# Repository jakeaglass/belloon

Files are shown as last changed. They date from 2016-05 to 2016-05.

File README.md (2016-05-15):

##Belloon &ndash; Bellarmine College Prep's High Altitude Balloon Project &ndash; Code, Schematics, and PCB Layout

Launching in ~~winter~~ summer of 2016 (targeting ~~January~~ June) to ~35km of altitude with a 1600g Hydrogen-filled latex balloon and a sensor package complete with the following:

- Camera (GoPro HERO))
- 144.390MHz APRS RadioMetrix Radio for telemetry
- GPS tracker (model TBD)
- ATMega CPU (with Arduino bootloader) with SD card for data logging
- Gas sensors (a sensor that can detect carbon-based gases and nitrous oxide, some of the worse pollutants in the atmosphere that also cause smog)
- Humidity Sensor
- Temperature Sensor

Once the balloon's payload&mdash;the board and sensors&mdash;is complete, we'll be able to launch and make use of the data collected to study environmental changes in the Earth’s atmosphere. Launch will be carried out with the help of the California Near Space Project, which has volunteered to facilitate the launch and retrieval. 

The board design is complete as of May 12 and has been sent off to be fabricated, so it will be debugged in person shortly. See the updated files for the full schematic and board (both done in EAGLE), gerber files, and BOM.

 &ndash; [Jake Glass](http://jake.glass) & [Mihir Trivedi](http://mihirtrivedi.com/)

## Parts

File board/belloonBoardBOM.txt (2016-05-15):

Partlist

Exported from sensorBoardSchematic2.brd at 5/11/2016 8:02 PM

EAGLE Version 7.5.0 Copyright (c) 1988-2015 CadSoft

Assembly variant: 

Part              Value             Package             Library                  Position (inch)       Orientation

AN1               ANT-NSG4712-6     ANT-NSG4712-6       roundsolutions           (0.2 0.45)            R0
BAROMETER         MPL115A           LGA8                SparkFun-Sensors         (1.2 0.45)            R180
C1                100uF             EIA7343             SparkFun-Capacitors      (3.3 0.25)            R90
C2                100uF             EIA7343             SparkFun-Capacitors      (3.2 0.95)            R0
C3                10uF              EIA3216             SparkFun-Retired         (3.2 0.75)            R0
C4                10uF              EIA3216             SparkFun-Retired         (3.55 0.2)            R90
C5                0.1uF             0402-CAP            SparkFun-Retired         (3.7 0.2)             R270
C6                0.1uF             0402-CAP            SparkFun-Retired         (3.3 0.6)             R0
C7                47uF              EIA3528             SparkFun-Capacitors      (1.8 2.15)            R90
C8                0.1uF             0603-CAP            SparkFun-Capacitors      (2 1.85)              R270
C9                47uF              EIA3528             SparkFun-Capacitors      (3.6 1.05)            R0
C10               47uF              EIA3528             SparkFun-Capacitors      (3.05 0.2)            R90
C11               20pF              C0402               resistor                 (1.65 0.95)           R270
C12               20pF              C0402               resistor                 (1.4 0.95)            R270
C13               1.0uF             0603-CAP            SparkFun-Capacitors      (1.15 1.45)           R0
C14               0.1uF             0603-CAP            SparkFun-Capacitors      (2.6 0.7)             R180
C15               0.1uF             0603-CAP            SparkFun-Capacitors      (1.4 0.4)             R180
C16               1.0uF             0603-CAP            SparkFun-Capacitors      (1.35 0.65)           R0
C17               10uF              0603-CAP            SparkFun-Capacitors      (0.6 1.15)            R90
C18               10uF              0603-CAP            SparkFun-Capacitors      (2.6 0.85)            R180
C19               10uF              0603-CAP            SparkFun-Capacitors      (1.4 0.5)             R180
C20               10uF              0603-CAP            SparkFun-Capacitors      (2.15 1.85)           R270
C21               0.1uF             0603-CAP            SparkFun-Capacitors      (2.05 1.6)            R90
C22               10uF              0603-CAP            SparkFun-Capacitors      (0.6 1.5)             R90
C23               .1uF              0603-CAP            SparkFun-Capacitors      (0.75 1.5)            R90
C24               10uF              0603-CAP            SparkFun-Capacitors      (2.15 0.25)           R180
C25               10uF              0603-CAP            SparkFun-Capacitors      (1.65 0.25)           R180
C26               10uF              0603-CAP            SparkFun-Capacitors      (0.5 0.15)            R90
C27               0.1uF             0402-CAP            SparkFun-Retired         (3 1.45)              R270
C28               0.1uF             0603-CAP            SparkFun-Capacitors      (1.3 1.95)            R180
CASE_GROUND_PLANE                   3,81/1,4            wirepad                  (0.5 2.4)             R0
HUMIDITY          HDC1050           TI-S-PWSON-N6       Ava                      (2.75 0.8)            R90
IC1               RXM-GPS-FM        SMD-22              linx-addl                (0.95 0.6)            R270
JP1                                 1X06                pinhead                  (0.35 1.95)           R90
JP2                                 1X08                pinhead                  (0.15 2.05)           R90
L1                10uH              1007                SparkFun-Passives        (2.15 1.6)            R0
LM1117I_3.3V                        SOT223              SparkFun-PowerIC         (2.75 0.2)            R90
LM1117I_5V                          SOT223              SparkFun-PowerIC         (3.2 1.25)            R0
MPU               ATMEGA32U4TQFP-44 TQFP44              SparkFun-DigitalIC       (1.65 1.65)           R0
Q1                8MHz              HC49U70             crystal                  (1.55 1.2)            R0
R1                82                0402-RES            SparkFun-Passives        (2.05 0.8)            R270
R2                51                0402-RES            SparkFun-Passives        (1.7 0.7)             R90
R3                82                0402-RES            SparkFun-Passives        (2.15 0.7)            R270
R4                47k               0402-RES            SparkFun-Passives        (2.3 0.75)            R90
R5                22                0402-RES            SparkFun-Passives        (0.85 1.4)            R180
R6                22                0402-RES            SparkFun-Passives        (0.9 1.2)             R180
R7                4.7k              0402-RES            SparkFun-Passives        (2.3 0.95)            R270
R8                4.7k              0402-RES            SparkFun-Passives        (2.15 0.95)           R270
R9                22k               0402-RES            SparkFun-Passives        (2.4 0.75)            R90
R10               82                0402-RES            SparkFun-Passives        (1.8 0.7)             R270
R11               10k               0402-RES            SparkFun-Passives        (1.6 0.7)             R90
S1                                  TACTILE-PTH         SparkFun-Retired         (2.6 1.2)             R0
T1                                  SOT-23              zetex                    (1.95 0.65)           R180
U$1               RADIOMETRIX-HX1   RADIOMETRIX-HX1     Ava                      (1.55 2.75)           R0
U$2               MICS-4514         MICS_10-SMD         SparkFun-Sensors         (2.2 0.45)            R0
U$3               MICS-2614         MICS_10-SMD         SparkFun-Sensors         (1.75 0.45)           R0
U1                                  SOT95P275X110-6N    NXP_By_element14_Batch_1 (0.65 1.3)            R0
V_BATT_6V                           SCREWTERMINAL-5MM-2 SparkFun-Connectors      (3.7 0.8)             MR270
X1                APRS_ANT          R141426             con-coax                 (0.35 2.85)           R0
X2                USB_PGRM          32005-201           con-cypressindustries    (0.3 1.3)             R0
X3                SDBMF             SDBMF-009XXBXX2     farnell                  (3.3 2.45)            R180

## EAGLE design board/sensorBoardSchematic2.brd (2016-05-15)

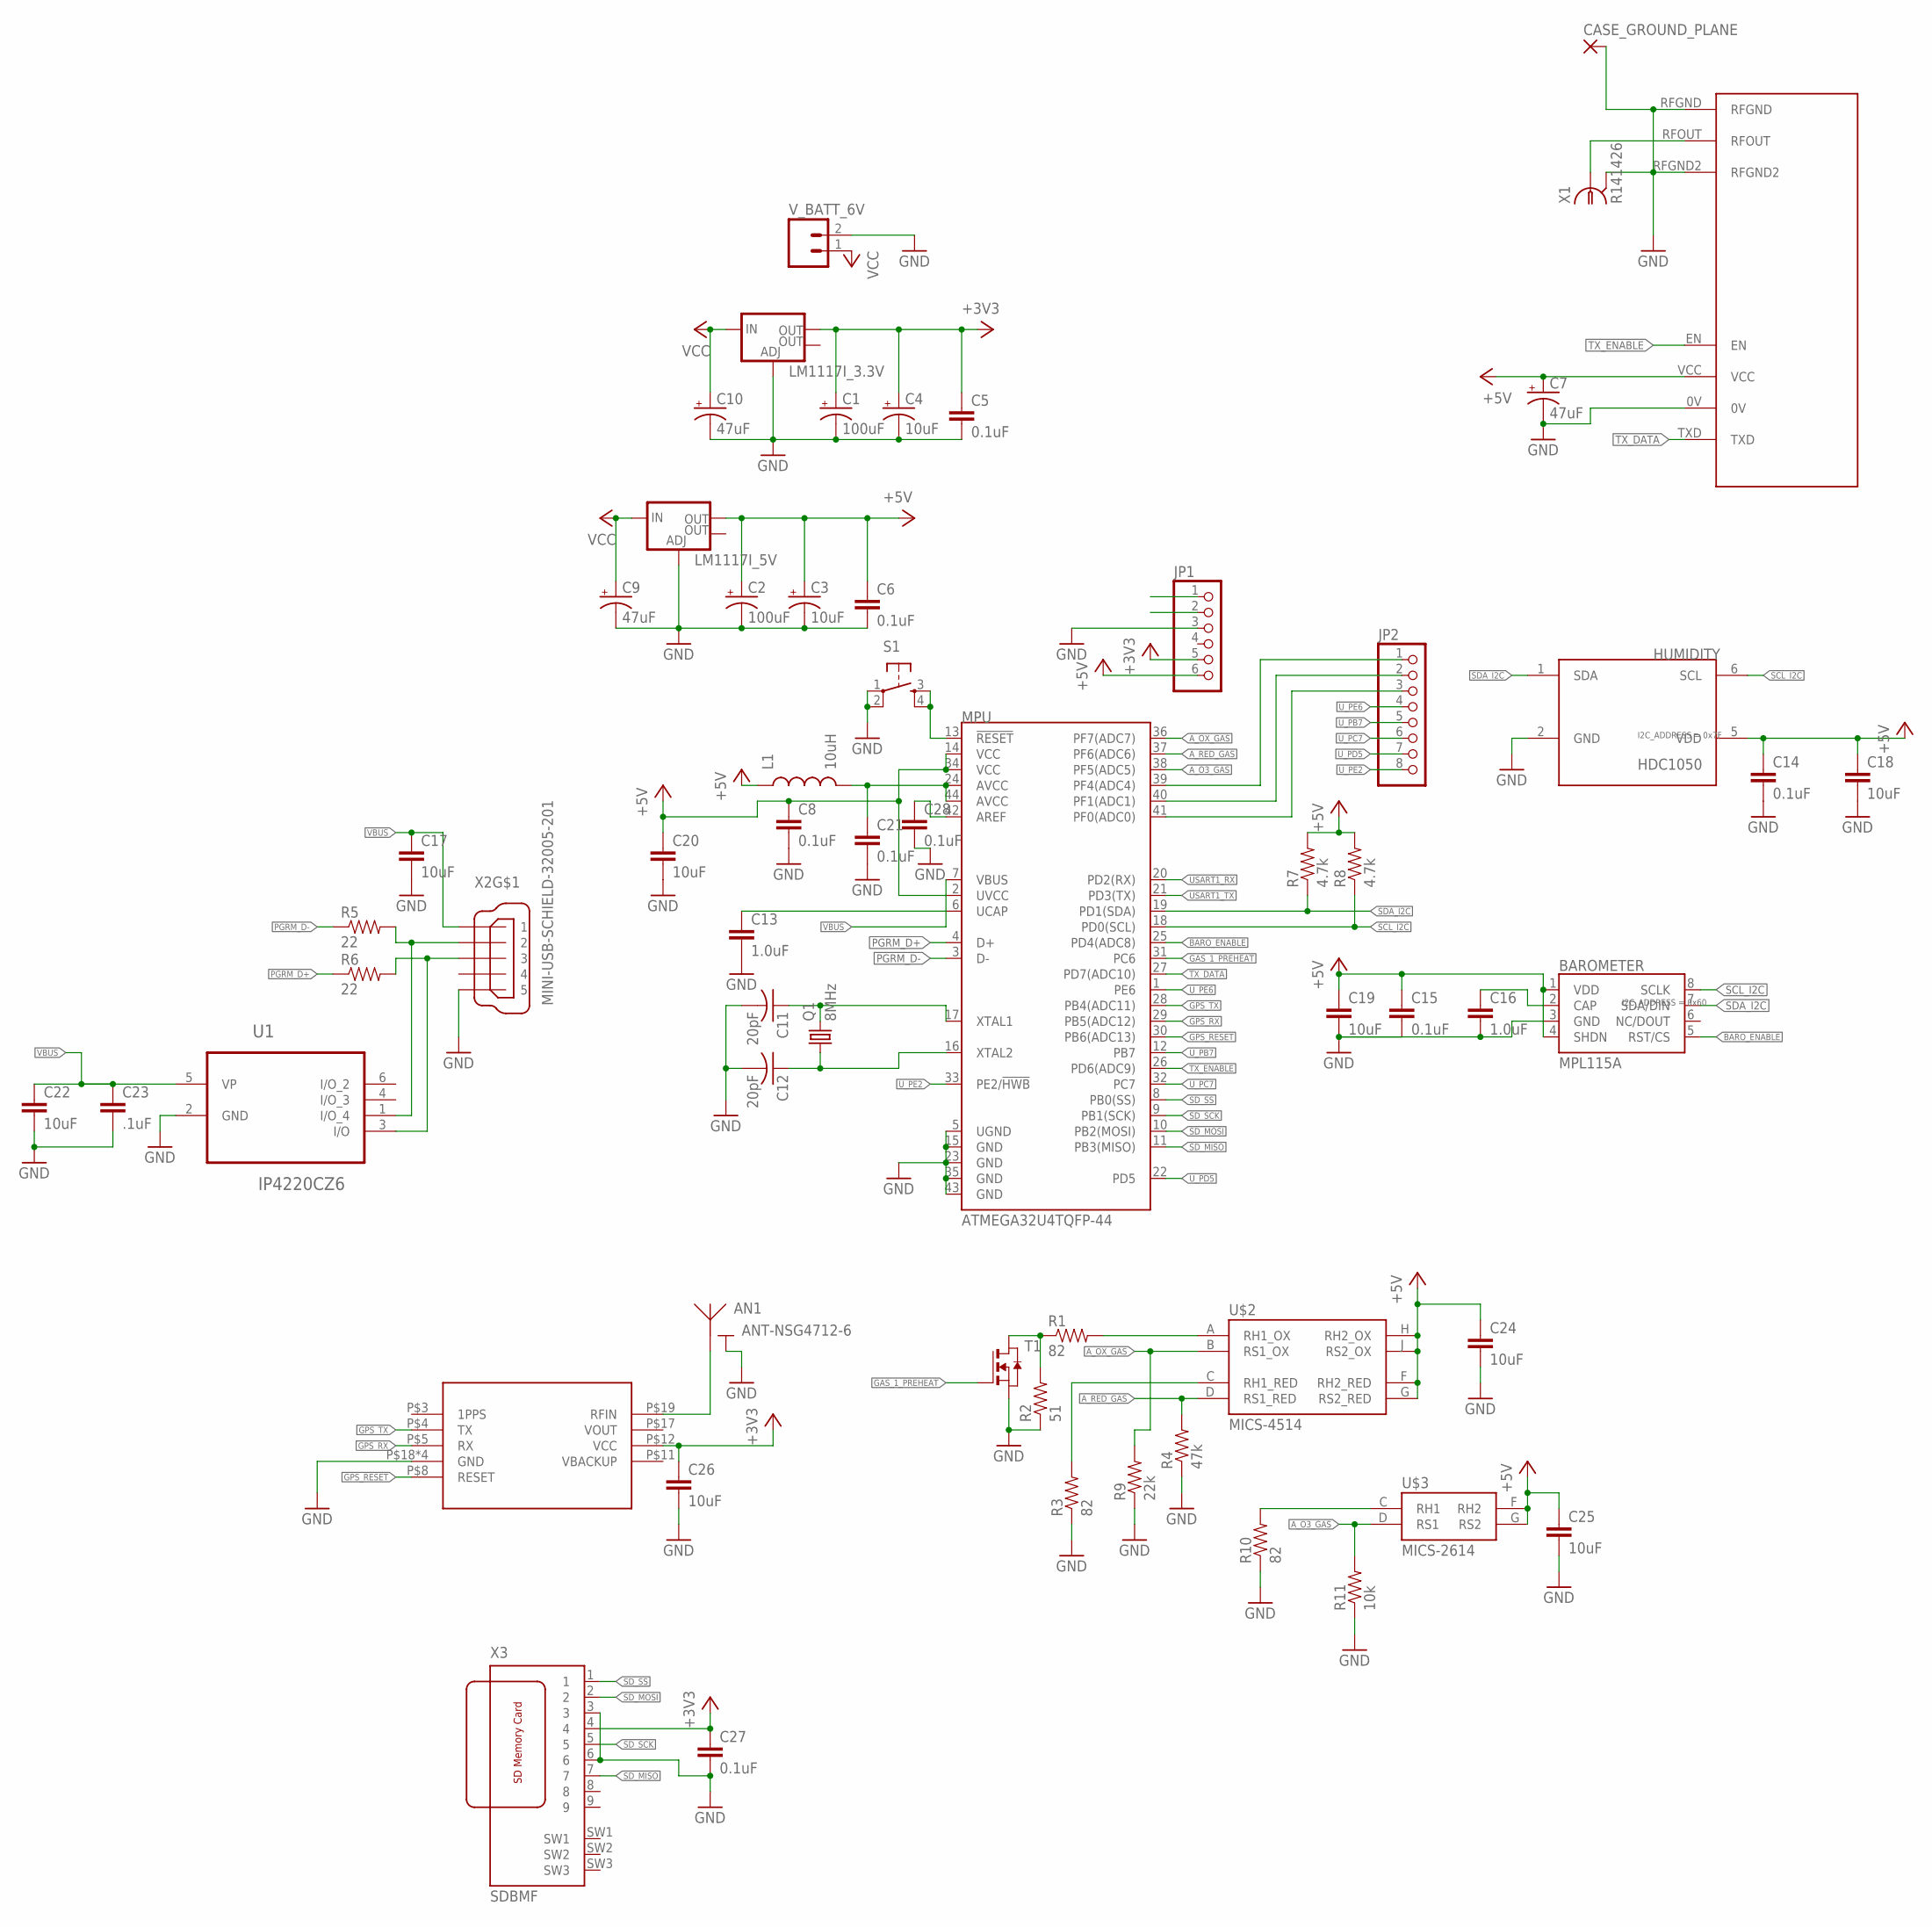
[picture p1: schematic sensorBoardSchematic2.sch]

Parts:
AN1: ANT-NSG4712-6
BAROMETER: MPL115A; LGA8
C1, C2: 100uF; EIA7343
C3, C4: 10uF; EIA3216
C5, C6, C27: 0.1uF; 0402-CAP
C7, C9, C10: 47uF; EIA3528
C8, C14, C15, C21, C28: 0.1uF; 0603-CAP
C11, C12: 20pF; C0402
C13, C16: 1.0uF; 0603-CAP
C17, C18, C19, C20, C22, C24, C25, C26: 10uF; 0603-CAP
C23: .1uF; 0603-CAP
CASE_GROUND_PLANE: 3,81/1,4
HUMIDITY: HDC1050; TI-S-PWSON-N6
IC1: RXM-GPS-FM; SMD-22
JP1: PINHD-1X6; 1X06
JP2: PINHD-1X8; 1X08
L1: 10uH; 1007
LM1117I_3.3V, LM1117I_5V: V_REG_LM1117SOT223; SOT223
MPU: ATMEGA32U4TQFP-44; TQFP44
Q1: 8MHz; HC49U70
R1, R3, R10: 82; 0402-RES
R2: 51; 0402-RES
R4: 47k; 0402-RES
R5, R6: 22; 0402-RES
R7, R8: 4.7k; 0402-RES
R9: 22k; 0402-RES
R11: 10k; 0402-RES
S1: TAC_SWITCHPTH; TACTILE-PTH
T1: NMOSSOT23; SOT-23
U1: IP4220CZ6; SOT95P275X110-6N
U$1: RADIOMETRIX-HX1
U$2: MICS-4514; MICS_10-SMD
U$3: MICS-2614; MICS_10-SMD
V_BATT_6V: M025MM; SCREWTERMINAL-5MM-2
X1: R141426
X2: MINI-USB-SCHIELD-32005-201; 32005-201
X3: SDBMF; SDBMF-009XXBXX2

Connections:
+3V3: C1.A (+), C4.A (+), C5.1, C26.1, C27.1, IC1.P$12 (VCC), JP1.5, LM1117I_3.3V.2 (OUT), X3.4
+5V: BAROMETER.1 (VDD), BAROMETER.4 (SHDN), C2.A (+), C3.A (+), C6.1, C7.A (+), C8.1, C14.1, C15.1, C18.1, C19.1, C20.1, C24.1, C25.1, HUMIDITY.5 (VDD), JP1.6, L1.1, LM1117I_5V.2 (OUT), MPU.2 (UVCC), MPU.14 (VCC), MPU.34 (VCC), R7.2, R8.2, U$1.VCC, U$2.F (RH2_RED), U$2.G (RS2_RED), U$2.H (RH2_OX), U$2.J (RS2_OX), U$3.F (RH2), U$3.G (RS2)
A_O3_GAS: MPU.38 (PF5(ADC5)), R11.2, U$3.D (RS1)
A_OX_GAS: MPU.36 (PF7(ADC7)), R9.2, U$2.B (RS1_OX)
A_RED_GAS: MPU.37 (PF6(ADC6)), R4.2, U$2.D (RS1_RED)
BARO_ENABLE: BAROMETER.5 (RST/CS), MPU.25 (PD4(ADC8))
GAS_1_PREHEAT: MPU.31 (PC6), T1.3 (G)
GND: AN1.G@1 (G), AN1.G@2 (G), AN1.G@3 (G), AN1.G@4 (G), AN1.G@5 (G), AN1.G@6 (G), AN1.G@7 (G), AN1.G@8 (G), AN1.G@9 (G), AN1.G@10 (G), BAROMETER.3 (GND), C1.C (-), C2.C (-), C3.C (-), C4.C (-), C5.2, C6.2, C7.C (-), C8.2, C9.C (-), C10.C (-), C11.2, C12.2, C13.2, C14.2, C15.2, C16.2, C17.2, C18.2, C19.2, C20.2, C21.2, C22.2, C23.2, C24.2, C25.2, C26.2, C27.2, C28.2, CASE_GROUND_PLANE.1, HUMIDITY.2 (GND), IC1.P$18 (GND), IC1.P$20 (GND), IC1.P$21 (GND), IC1.P$22 (GND), JP1.3, LM1117I_3.3V.1 (ADJ), LM1117I_5V.1 (ADJ), MPU.5 (UGND), MPU.15 (GND), MPU.23 (GND), MPU.35 (GND), MPU.43 (GND), R2.1, R3.1, R4.1, R9.1, R10.1, R11.1, S1.1, S1.2, T1.2 (S), U1.2 (GND), U$1.0V, U$1.RFGND, U$1.RFGND2, V_BATT_6V.2, X1.2, X1.3 (2), X1.4 (2), X1.5 (2), X2.5, X3.3, X3.6
GPS_RESET: IC1.P$8 (RESET), MPU.30 (PB6(ADC13))
GPS_RX: IC1.P$5 (RX), MPU.29 (PB5(ADC12))
GPS_TX: IC1.P$4 (TX), MPU.28 (PB4(ADC11))
unnamed: MPU.13 (!RESET), S1.3, S1.4
unnamed: U$1.RFOUT, X1.1
unnamed: AN1.A (ANT), IC1.P$19 (RFIN)
unnamed: C21.1, L1.2, MPU.24 (AVCC), MPU.44 (AVCC)
unnamed: R1.2, U$2.A (RH1_OX)
unnamed: C11.1, MPU.17 (XTAL1), Q1.2
unnamed: BAROMETER.2 (CAP), C16.1
unnamed: C12.1, MPU.16 (XTAL2), Q1.1
unnamed: R5.2, U1.1 (I/O_4), X2.2
unnamed: R6.2, U1.3 (I/O), X2.3
unnamed: C13.1, MPU.6 (UCAP)
unnamed: R1.1, R2.2, T1.1 (D)
unnamed: JP2.1, MPU.39 (PF4(ADC4))
unnamed: R10.2, U$3.C (RH1)
unnamed: JP2.2, MPU.40 (PF1(ADC1))
unnamed: JP2.3, MPU.41 (PF0(ADC0))
unnamed: R3.2, U$2.C (RH1_RED)
unnamed: C28.1, MPU.42 (AREF)
PGRM_D+: MPU.4 (D+), R6.1
PGRM_D-: MPU.3 (D-), R5.1
SCL_I2C: BAROMETER.8 (SCLK), HUMIDITY.6 (SCL), MPU.18 (PD0(SCL)), R8.1
SDA_I2C: BAROMETER.7 (SDA/DIN), HUMIDITY.1 (SDA), MPU.19 (PD1(SDA)), R7.1
SD_MISO: MPU.11 (PB3(MISO)), X3.7
SD_MOSI: MPU.10 (PB2(MOSI)), X3.2
SD_SCK: MPU.9 (PB1(SCK)), X3.5
SD_SS: MPU.8 (PB0(SS)), X3.1
TX_DATA: MPU.27 (PD7(ADC10)), U$1.TXD
TX_ENABLE: MPU.26 (PD6(ADC9)), U$1.EN
USART1_RX: JP1.1, MPU.20 (PD2(RX))
USART1_TX: JP1.2, MPU.21 (PD3(TX))
U_PB7: JP2.5, MPU.12 (PB7)
U_PC7: JP2.6, MPU.32 (PC7)
U_PD5: JP2.7, MPU.22 (PD5)
U_PE2: JP2.8, MPU.33 (PE2/!HWB)
U_PE6: JP2.4, MPU.1 (PE6)
VBUS: C17.1, C22.1, C23.1, MPU.7 (VBUS), U1.5 (VP)
VCC: C9.A (+), C10.A (+), LM1117I_3.3V.3 (IN), LM1117I_5V.3 (IN), V_BATT_6V.1

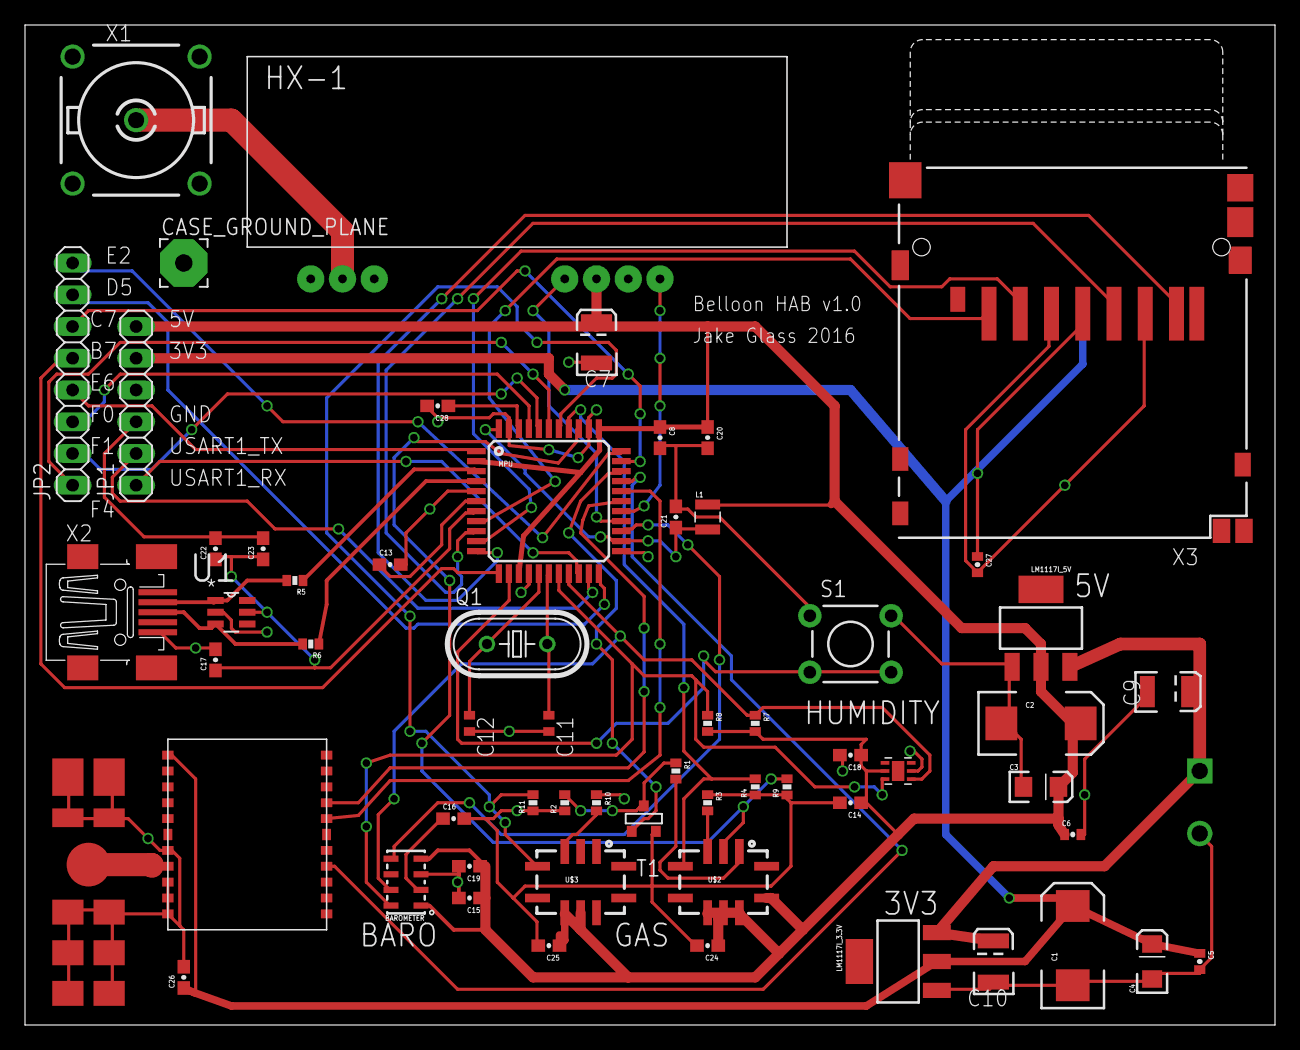
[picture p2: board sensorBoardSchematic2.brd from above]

Board: 2 copper layers, 100.0 x 80.0 mm, 61 parts (1 on the bottom side), 48 nets.

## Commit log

2015-11-24 initial commit of partially-complete sensor board
    [sensorBoardSchematic.sch]
2016-02-23 huge progress on sensor board schematic; configured USB, ESD isolation for USB, radio (note: need to figure out specs for digital packets from MPU), sensor IC's; analogue sensors and gas sensors need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
    [sensorBoardSchematic.sch]
2016-05-15 finished board v1, schematics and board layout, which should be sync'd up now
    [sensorBoardSchematic2.brd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]

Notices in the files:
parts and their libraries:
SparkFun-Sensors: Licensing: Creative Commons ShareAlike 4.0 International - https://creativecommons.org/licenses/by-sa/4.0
